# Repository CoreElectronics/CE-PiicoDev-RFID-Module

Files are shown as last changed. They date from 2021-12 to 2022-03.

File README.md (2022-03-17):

# PiicoDev® RFID Module



This is the repo for the Core Electronics [PiicoDev RFID Module](https://core-electronics.com.au/catalog/product/view/sku/CE08086).

The PiicoDev® RFID Module will get you started with reading (and writing) RFID tags. Use unique tag IDs to identify users, track your equipment, or make your own vending machine. Getting started is easy - there's no need for soldering, and great PiicoDev guides for Python / MicroPython. If you prefer to go freestyle, each RFID module features a standard breakout header for breadboarding or wires, and the small size makes it ideal for compact projects. This module is compatible with modern RFID / NFC tags: NTAG213, NTAG203 and Classic (aka. Mifare) tags. That means you can not only read the tag ID, but also read or write data to the tag. For more advanced projects, you can connect up to four RFID modules on a single bus. Each device address is selectable using the address switch (labelled ASW) which can select addresses from 0x2C (factory default) to 0x2F.

**Features**

- Small size to fit your project
- Read IDs and Read/Write data to your tag
- Connect up to four RFID modules on the same bus
- Great guides to get you started
- PiicoDev connector, compatible with Qwiic and STEMMA QT (3.3V only)
- 2.54mm breakout for breadboarding/prototyping
- Manufactured and supported in Australia by Core Electronics

## License
This project is open source - please review the LICENSE.md file for further licensing information.

If you have any technical questions, or concerns about licensing, please contact technical support on the [Core Electronics forums](https://forum.core-electronics.com.au/).

*\"PiicoDev\" and the PiicoDev logo are trademarks of Core Electronics Pty Ltd.*

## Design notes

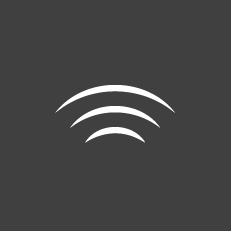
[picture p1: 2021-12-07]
Artwork/RFID SILK 2-01.png

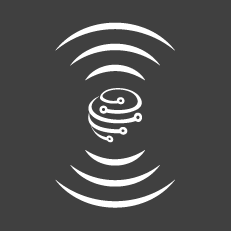
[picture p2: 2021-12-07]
Artwork/RFID SILK 1-01.png

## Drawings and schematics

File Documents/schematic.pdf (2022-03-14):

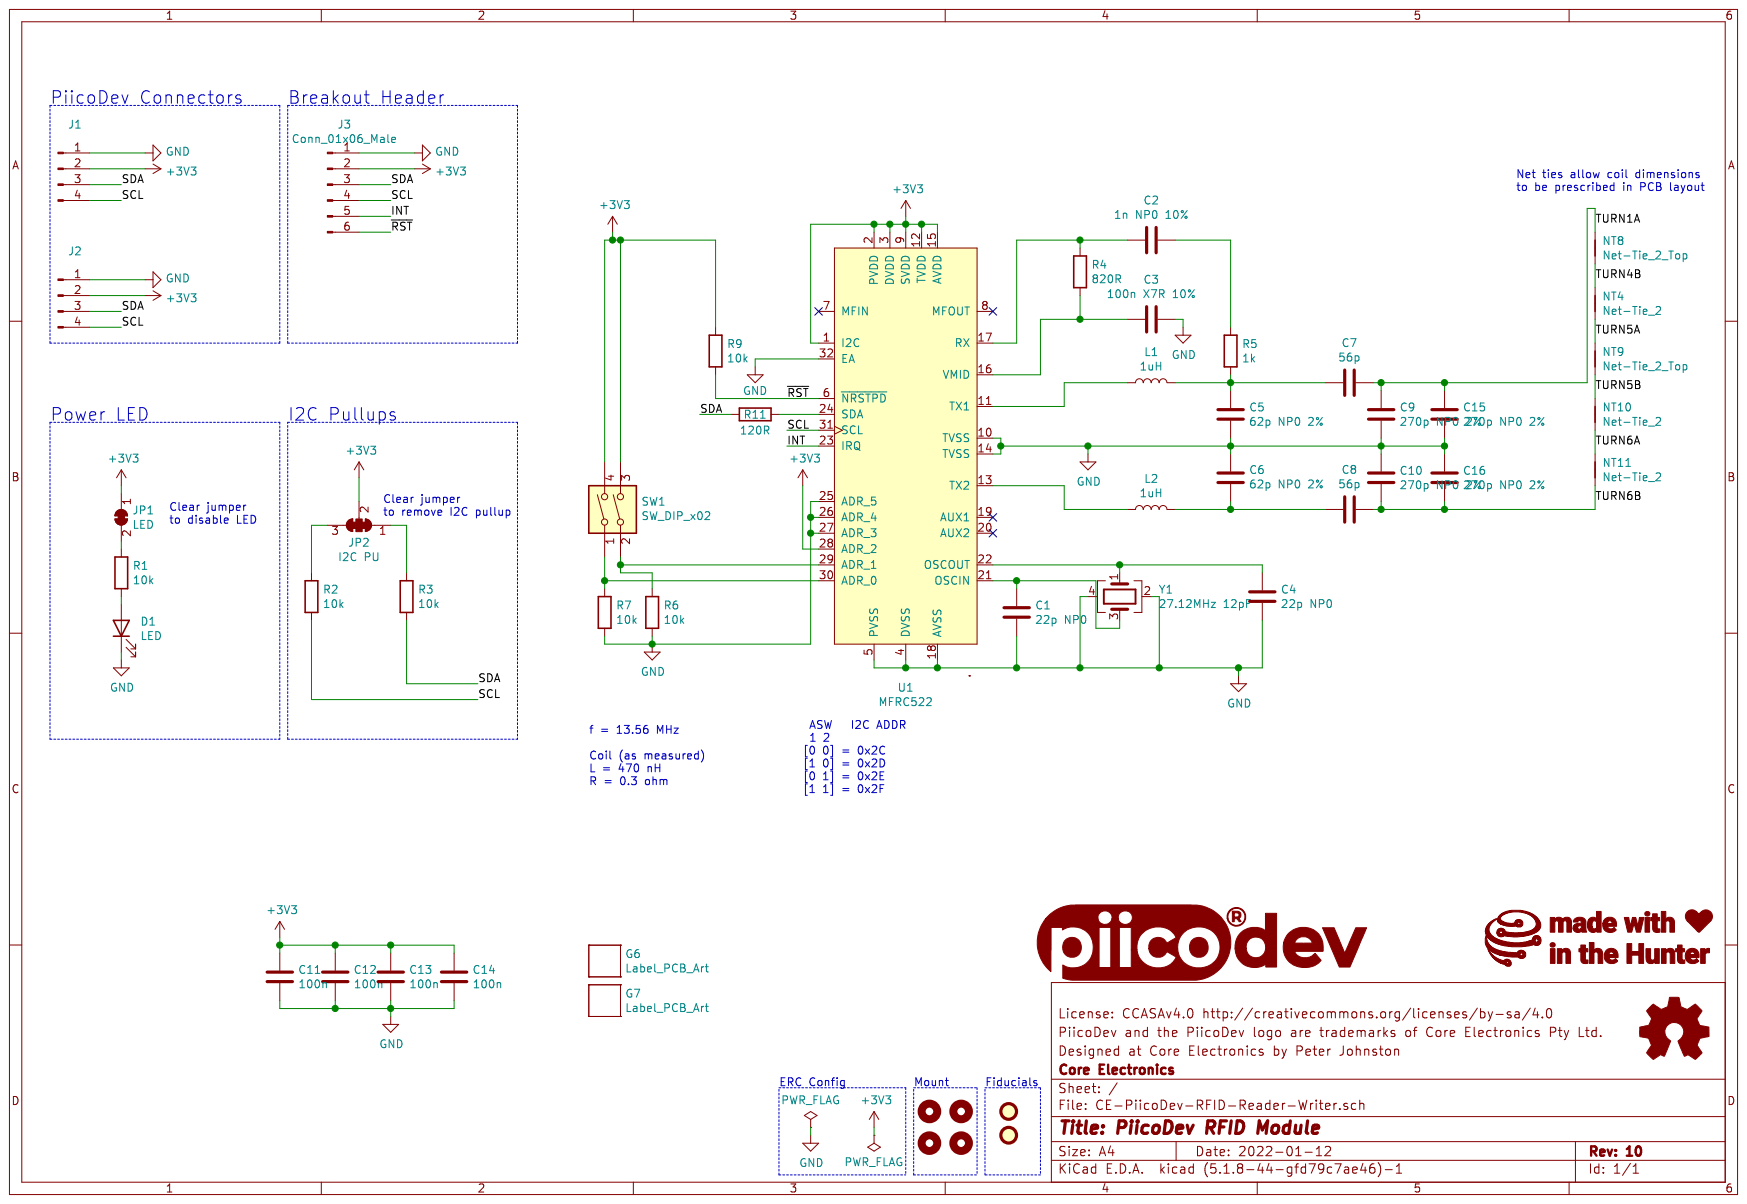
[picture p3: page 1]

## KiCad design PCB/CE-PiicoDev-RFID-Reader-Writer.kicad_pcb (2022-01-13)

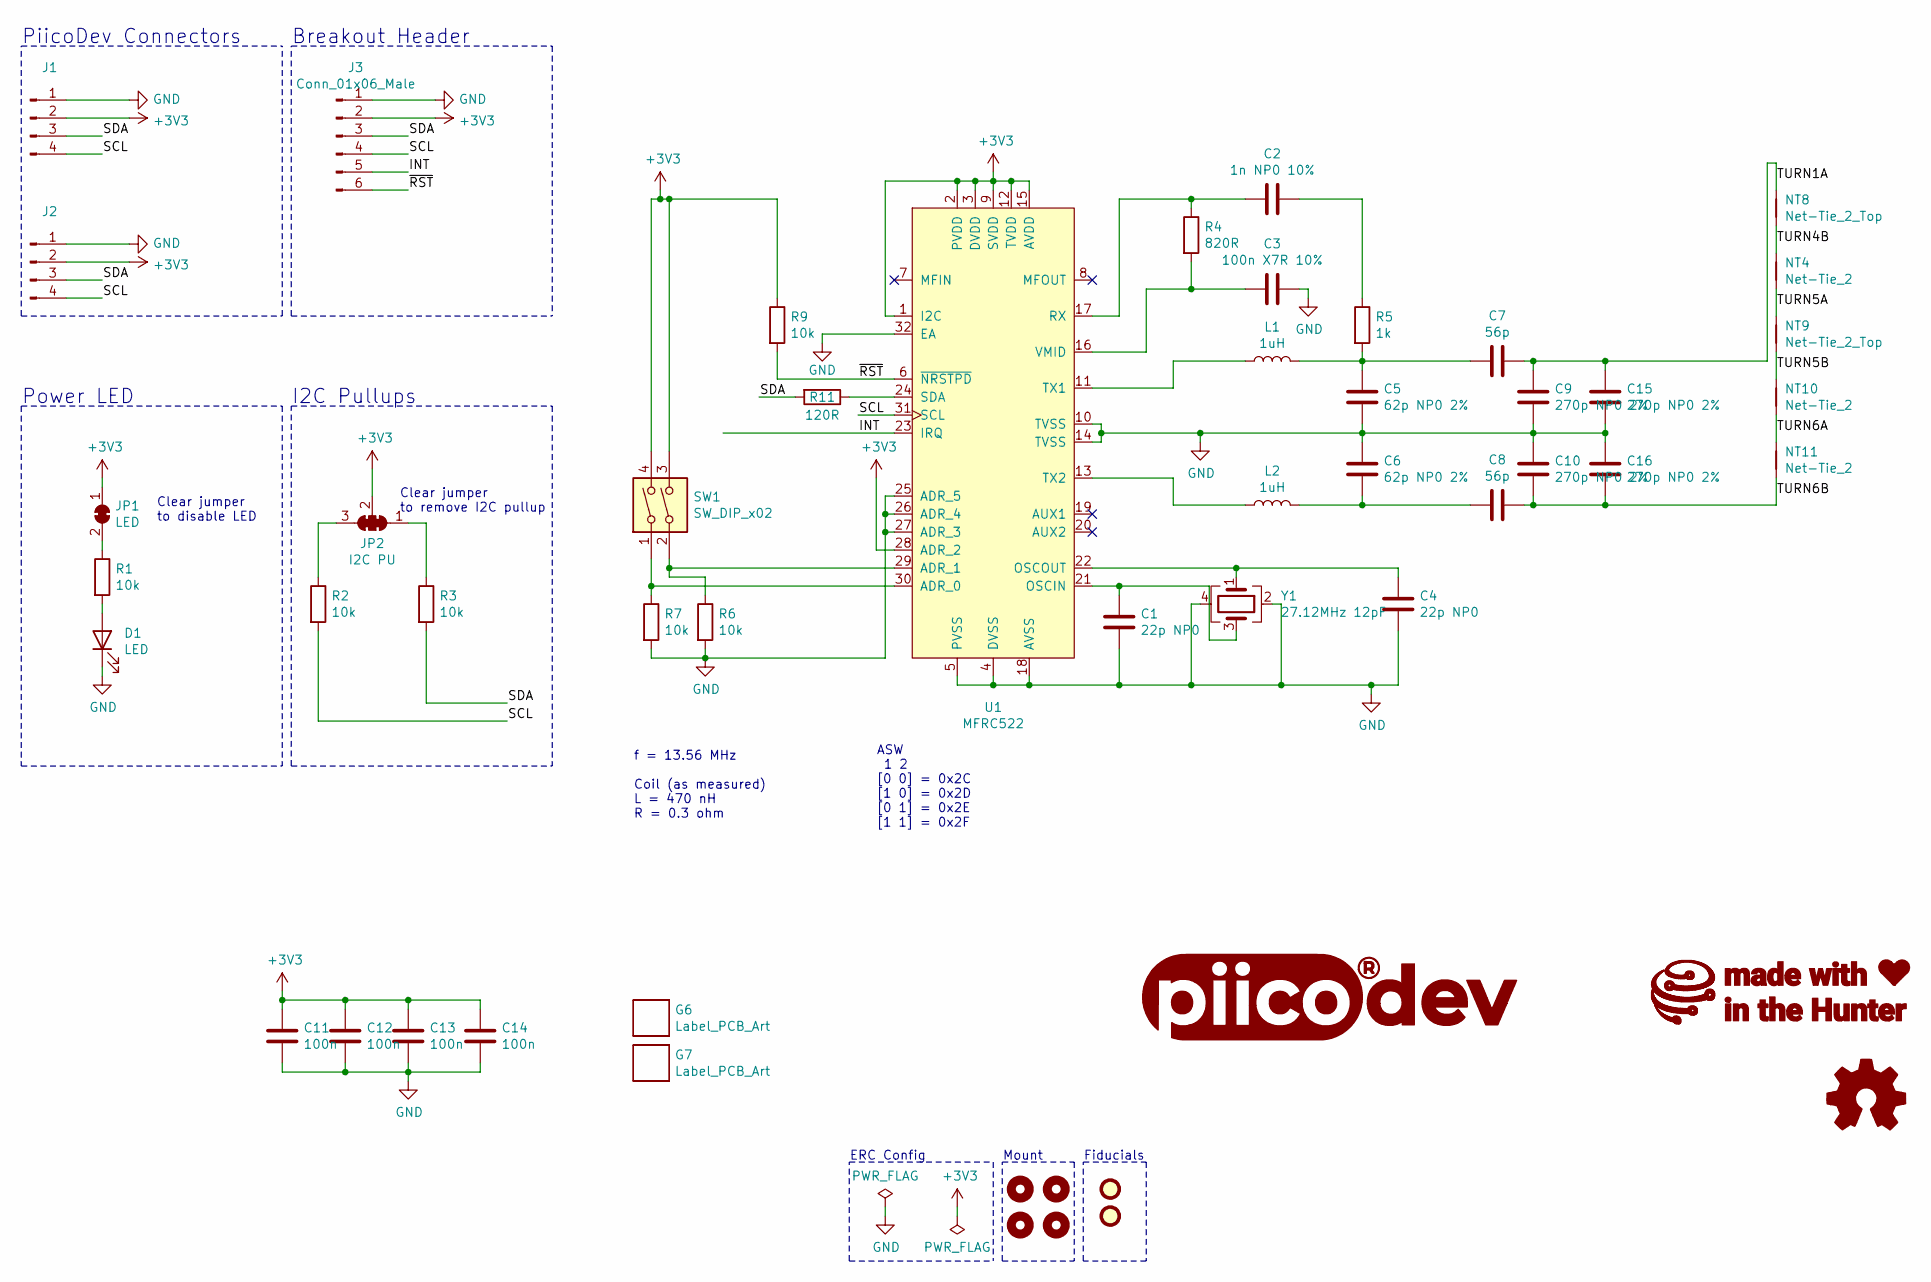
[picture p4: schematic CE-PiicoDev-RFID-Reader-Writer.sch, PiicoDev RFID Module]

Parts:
C1, C4: 22p NP0; C_0402_1005Metric
C2: 1n NP0 10%; C_0603_1608Metric
C3: 100n X7R 10%; C_0402_1005Metric
C5, C6: 62p NP0 2%; C_0603_1608Metric
C7, C8: 56p; C_0603_1608Metric
C9, C10, C15, C16: 270p NP0 2%; C_0603_1608Metric
C11, C12, C13, C14: 100n; C_0402_1005Metric
D1: LED; LED_0603_1608Metric
FID1, FID2: Fiducial; Fiducial_1mm_Mask2mm_No_Courtyard
G1: LOGO_PiicoDev; piicodev_logo_14.2x3.4mm
G2: LOGO_CoreElectronics_no-text
G3: LOGO_made-with-love; piicodev_logo_14.2x3.4mm
G6: Label_PCB_Art; Art_1
G7: Label_PCB_Art; Art_2
H1, H2, H3, H4: MountingHole; MountingHole_2.7mm_M2.5_PadClearance_1.2
J1, J2: JST_SH_SM04B-SRSS-TB_1x04-1MP_P1.00mm_Horizontal
J3: Conn_01x06_Male; PiicoDev_header_6pin
JP1: LED; SolderJumper-2_P1.3mm_Bridged_RoundedPad1.0x1.5mm
JP2: I2C PU; SolderJumper-3_P1.3mm_Closed_RoundedPad1.0x1.5mm_NumberLabe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
L1, L2: 1uH; L_0603_1608Metric
LOGO1: Logo_Open_Hardware_Small; oshw
NT4, NT10, NT11: Net-Tie_2; NetTie-2_SMD_Pad0.80mm
NT8, NT9: Net-Tie_2_Top; NetTie-2_SMD_Pad0.80mm
R1, R2, R3, R6, R7, R9: 10k; R_0402_1005Metric
R4: 820R; R_0603_1608Metric
R5: 1k; R_0603_1608Metric
R11: 120R; R_0402_1005Metric
SW1: SW_DIP_x02; SW_DIP_x02_Slide_CHS-02A1
U1: MFRC522; VQFN-32-1EP_5x5mm_P0.5mm_EP3.1x3.1mm_ThermalVias
Y1: 27.12MHz 12pF; Crystal_SMD_TXC_7M-4Pin_3.2x2.5mm

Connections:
+3V3: C11.1, C12.1, C13.1, C14.1, J1.2, J2.2, J3.2, JP1.1 (A), JP2.2 (C), R9.1, SW1.3, SW1.4, U1.1 (I2C), U1.2 (PVDD), U1.3 (DVDD), U1.9 (SVDD), U1.12 (TVDD), U1.15 (AVDD), U1.28 (ADR_2)
/INT: J3.5, U1.23 (IRQ)
/SCL: J1.4, J2.4, J3.4, R2.2, U1.31 (SCL)
/SDA: J1.3, J2.3, J3.3, R3.2, R11.2
/TURN1A: C7.1, C9.1, C15.1, NT8.1
/TURN4B: NT4.1, NT8.2
/TURN5A: NT4.2, NT9.1
/TURN5B: NT9.2, NT10.1
/TURN6A: NT10.2, NT11.1
/TURN6B: C8.1, C10.2, C16.2, NT11.2
/~RST: J3.6, R9.2, U1.6 (~NRSTPD); also elsewhere on the board
GND: C1.2, C3.1, C4.2, C5.2, C6.2, C9.2, C10.1, C11.2, C12.2, C13.2, C14.2, C15.2, C16.1, D1.1 (K), J1.1, J2.1, J3.1, R6.2, R7.2, U1.4 (DVSS), U1.5 (PVSS), U1.10 (TVSS), U1.14 (TVSS), U1.18 (AVSS), U1.25 (ADR_5), U1.26 (ADR_4), U1.27 (ADR_3), U1.32 (EA), Y1.2, Y1.4
unnamed: C1.1, U1.21 (OSCIN), Y1.3
unnamed: C2.1, R5.1
unnamed: C2.2, R4.1, U1.17 (RX)
unnamed: C3.2, R4.2, U1.16 (VMID)
unnamed: C4.1, U1.22 (OSCOUT), Y1.1
unnamed: C5.1, C7.2, L1.2, R5.2
unnamed: C6.1, C8.2, L2.2
unnamed: D1.2 (A), R1.2
unnamed: JP1.2 (B), R1.1
unnamed: JP2.1 (A), R3.1
unnamed: JP2.3 (B), R2.1
unnamed: L1.1, U1.11 (TX1)
unnamed: L2.1, U1.13 (TX2)
unnamed: R6.1, SW1.2, U1.29 (ADR_1)
unnamed: R7.1, SW1.1, U1.30 (ADR_0)
unnamed: R11.1, U1.24 (SDA)

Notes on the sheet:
ERC Config
Fiducials
Mount
PiicoDev Connectors
Breakout Header
Clear jumper to remove I2C pullup
I2C Pullups
Clear jumper to disable LED
Power LED
f = 13.56 MHz Coil (as measured) L = 470 nH R = 0.3 ohm
ASW 1 2 [0 0] = 0x2C [1 0] = 0x2D [0 1] = 0x2E [1 1] = 0x2F

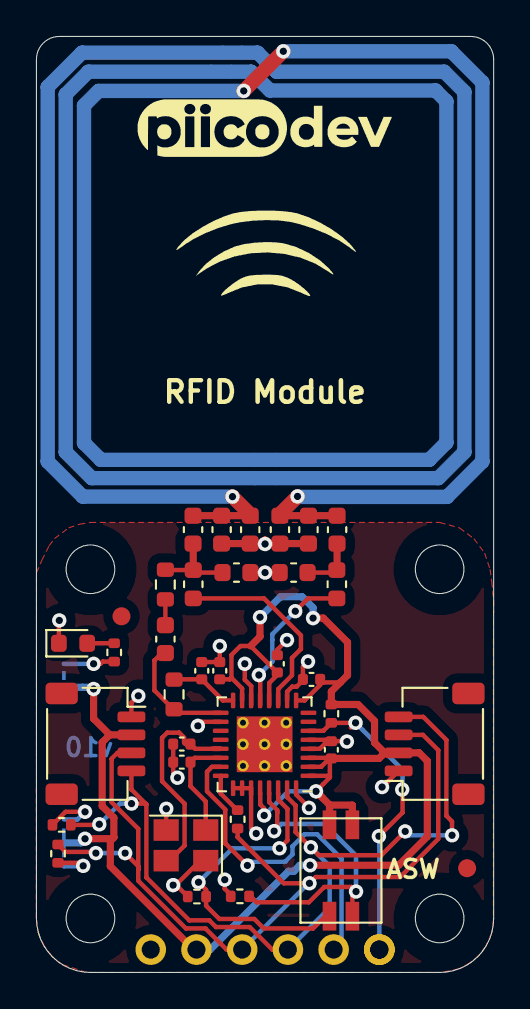
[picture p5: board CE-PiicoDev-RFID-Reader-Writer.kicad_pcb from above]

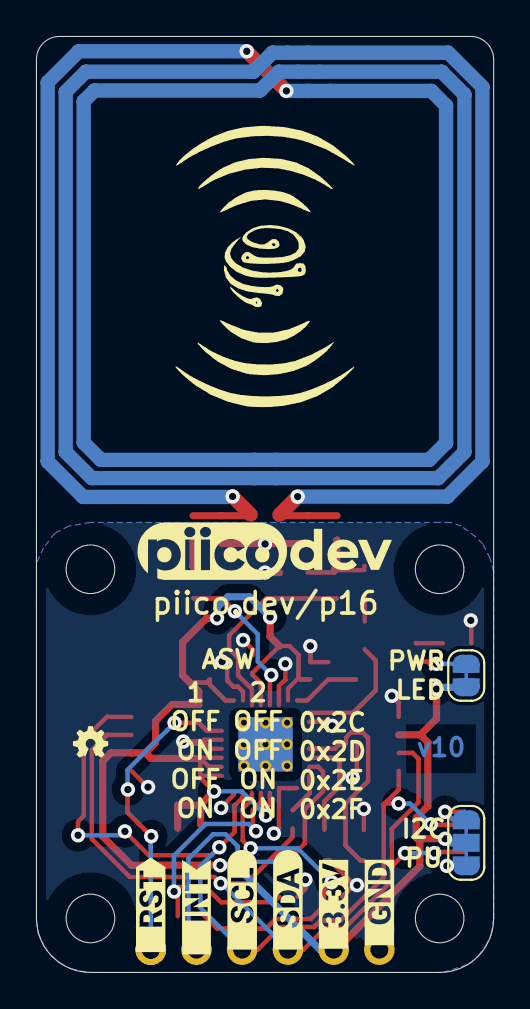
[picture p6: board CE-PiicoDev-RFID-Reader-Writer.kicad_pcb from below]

Board: 2 copper layers, 25.4 x 52.0 mm, 59 parts (16 on the bottom side), 28 nets.

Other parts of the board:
J4: Conn_01x01_Male; PiicoDev_header_1pin
kibuzzard-61B8280C, kibuzzard-61B8283F, kibuzzard-61B82819, kibuzzard-61B82827, kibuzzard-61B82831, kibuzzard-61B82849: G***; label

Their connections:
/~RST: J4.1; also elsewhere on the board

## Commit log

2021-09-08 Update all
    [CE-PiicoDev-RFID-Reader-Writer-MFRC522.kicad_pcb, CE-PiicoDev-RFID-Reader-Writer-MFRC522.sch]
2021-09-16 Add R10
    [CE-PiicoDev-RFID-Reader-Writer-MFRC522.kicad_pcb, CE-PiicoDev-RFID-Reader-Writer-MFRC522.sch]
2021-11-11 Change v00 to v01
    Halve the coil length.
    Make wider coil tracks.
    Add test points.
    Add I2C series resistor.
    Change inductors from 0402 to 0603.
    [CE-PiicoDev-RFID-Reader-Writer-MFRC522.kicad_pcb, CE-PiicoDev-RFID-Reader-Writer-MFRC522.sch]
2021-12-07 Improve Artwork
    [CE-PiicoDev-RFID-Reader-Writer-MFRC522.kicad_pcb, CE-PiicoDev-RFID-Reader-Writer-MFRC522.sch]
2021-12-14 Remove Interrupt LED and add DIP switches
    [CE-PiicoDev-RFID-Reader-Writer-MFRC522.kicad_pcb, CE-PiicoDev-RFID-Reader-Writer-MFRC522.sch]
2021-12-15 Rename Project
    [CE-PiicoDev-RFID-Reader-Writer.kicad_pcb, CE-PiicoDev-RFID-Reader-Writer.sch]
2021-12-21 Move via from directly under C14
    [CE-PiicoDev-RFID-Reader-Writer.kicad_pcb]
2021-12-23 Update DIP Switch Footprint
    [CE-PiicoDev-RFID-Reader-Writer.kicad_pcb, CE-PiicoDev-RFID-Reader-Writer.sch]
2022-01-06 Update PCB jumpers with thinner cut trace
    [CE-PiicoDev-RFID-Reader-Writer.kicad_pcb]
2022-01-12 v10 Release
    Remove testpoints
    Change ASW order so SW1 is LSB
    [CE-PiicoDev-RFID-Reader-Writer.kicad_pcb, CE-PiicoDev-RFID-Reader-Writer.sch]
2022-01-13 Move coil down 0.2mm
    Avoids issues with V-Cuts
    [CE-PiicoDev-RFID-Reader-Writer.kicad_pcb]
2022-01-13 Change R5 to 1k
    [CE-PiicoDev-RFID-Reader-Writer.kicad_pcb, CE-PiicoDev-RFID-Reader-Writer.sch]
2022-03-14 Add schematic.pdf and schematic comments
    [CE-PiicoDev-RFID-Reader-Writer.sch]

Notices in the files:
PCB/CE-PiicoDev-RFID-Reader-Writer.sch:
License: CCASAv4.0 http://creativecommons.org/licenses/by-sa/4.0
